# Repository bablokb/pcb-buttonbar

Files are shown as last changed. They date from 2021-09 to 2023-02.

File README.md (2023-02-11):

Project pcb-buttonbar
=====================

Overview
--------

This project contains the KiCAD files for a button-bar with
six buttons. Each button uses some additional hardware-components to
debounce the button:

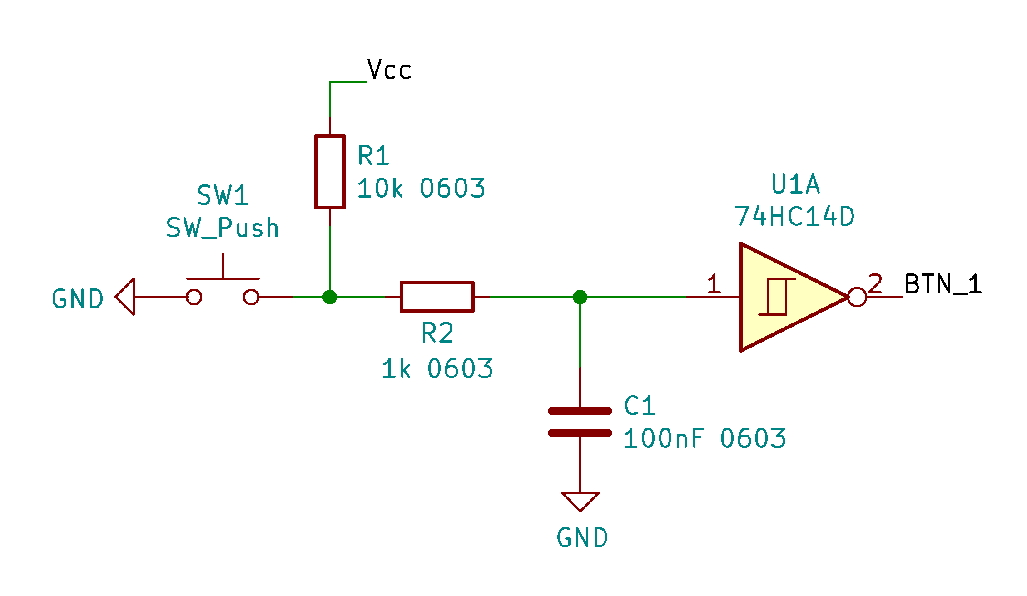
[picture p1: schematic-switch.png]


The buttons are pulled up using R1. R2 and C1 serve as a lowpass-filter,
i.e. high frequency bouncing is filtered out. The final inverter, a
74HC14 is a Schmitt-Trigger type inverter. This inverter switches from
high to low at a different level than from low to high (hysteresis),
so this will convert the curve from the RC-filter to sharp edge.

Goodies
-------

The buttonbar supports 6x6mm buttons and 12x12mm buttons. In addition
to the debounce-logic (bottom side of the pcb), there are optional
LEDs+resistors on the top.

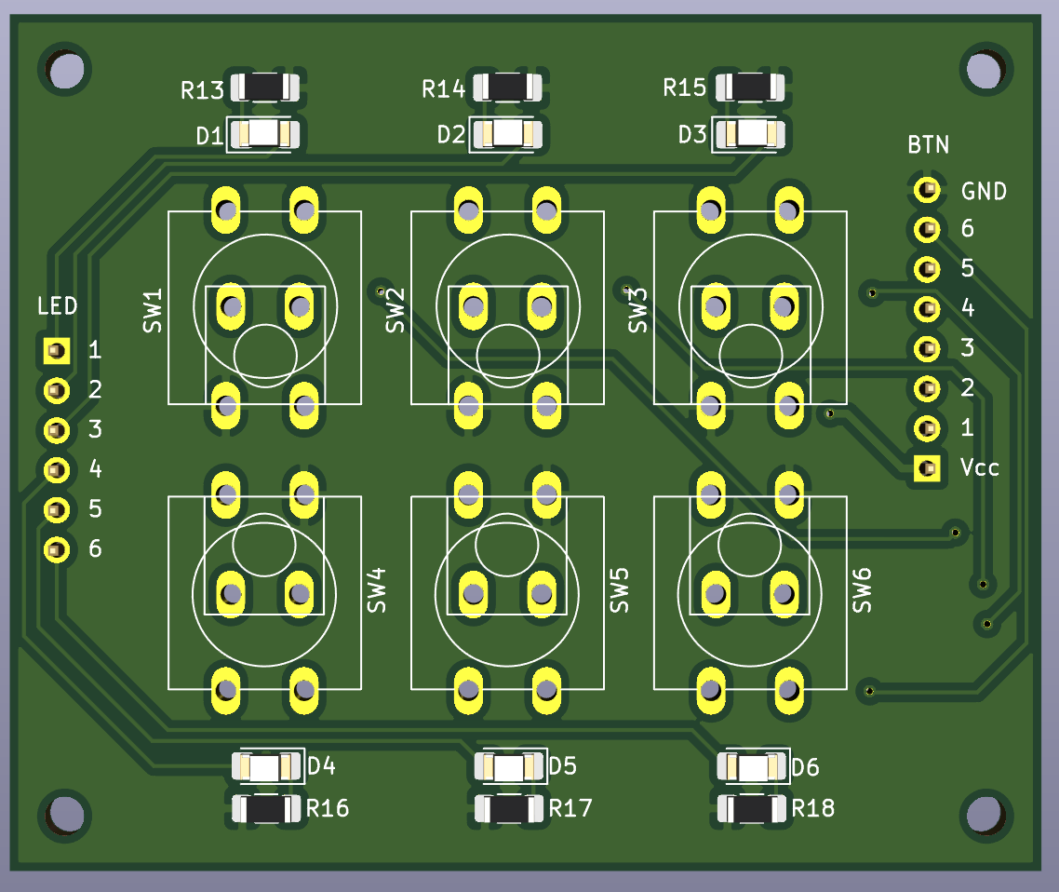
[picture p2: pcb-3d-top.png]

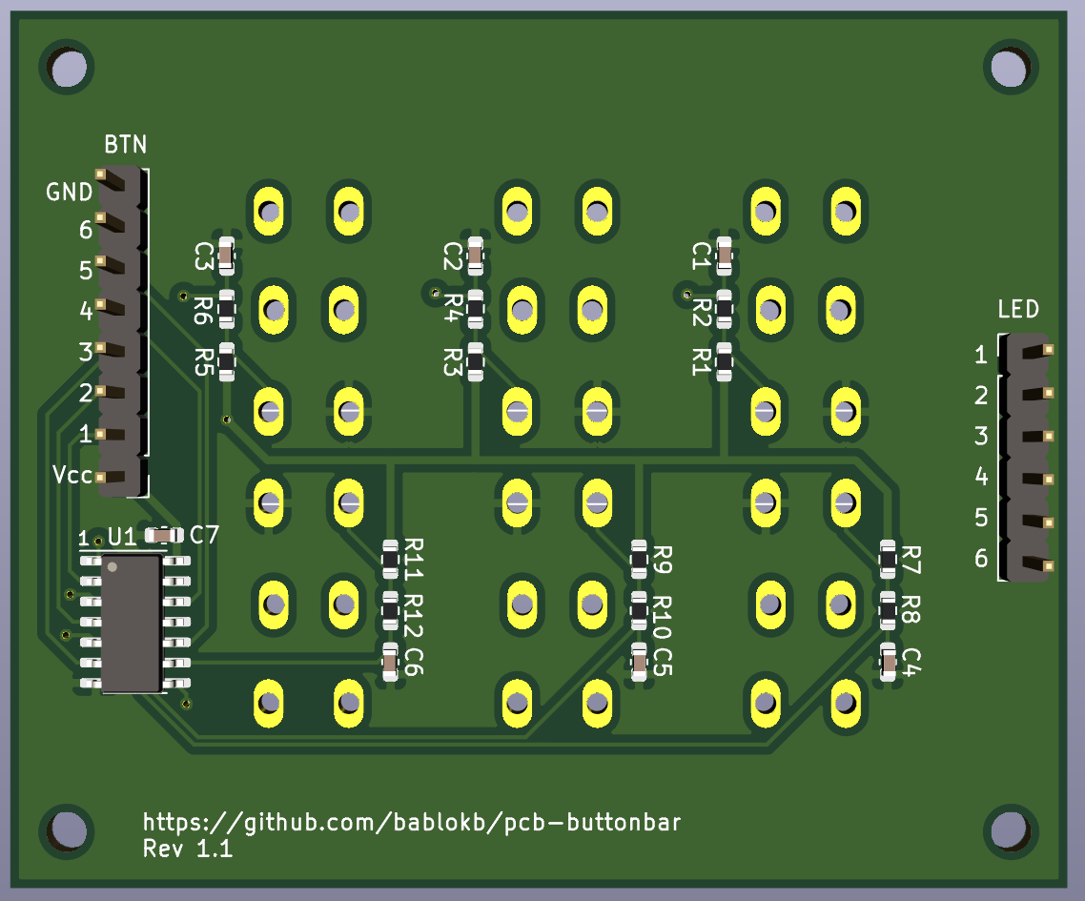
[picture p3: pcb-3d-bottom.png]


The footprints for the top-side are 1206, suitable for hand-soldering.
The bottom-side uses 0603, ideal for automatic assembly.

Checkout the branch "1x6-layout" for an alternatve button-layout.

Production Files
----------------

In the directory `production_files` you will find gerber-files, bom and cpl-file
suitable for JCLPCB. Migrating to a format suitable for your favorite
pcb-assembly service should be straightforward.

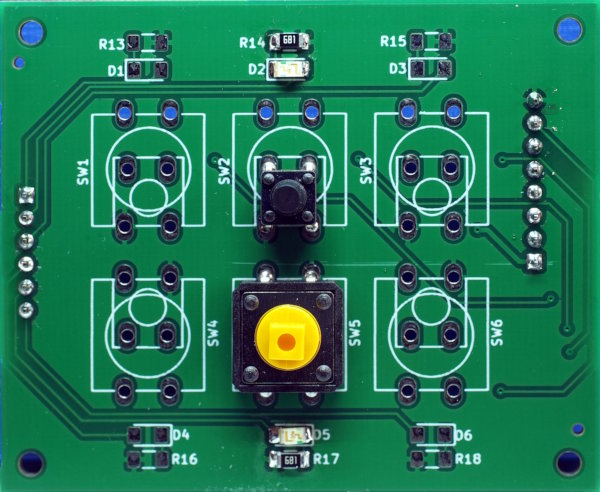
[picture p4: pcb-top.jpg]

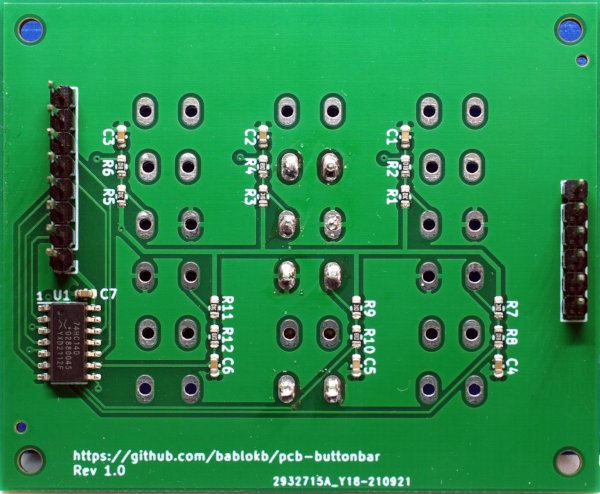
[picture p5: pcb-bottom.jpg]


Test Program
------------

The directory `src` contains a simple test program. Without the debouncing
in hardware, you would have to pass an additional parameter to the
Button-constructor for debouncing in software.

License
-------

Shield: [![CC BY-SA 4.0][cc-by-sa-shield]][cc-by-sa]

This work is licensed under a
[Creative Commons Attribution-ShareAlike 4.0 International
License][cc-by-sa].

[][cc-by-sa]

[cc-by-sa]: http://creativecommons.org/licenses/by-sa/4.0/
[cc-by-sa-image]: https://licensebuttons.net/l/by-sa/4.0/88x31.png
[cc-by-sa-shield]:
https://img.shields.io/badge/License-CC%20BY--SA%204.0-lightgrey.svg

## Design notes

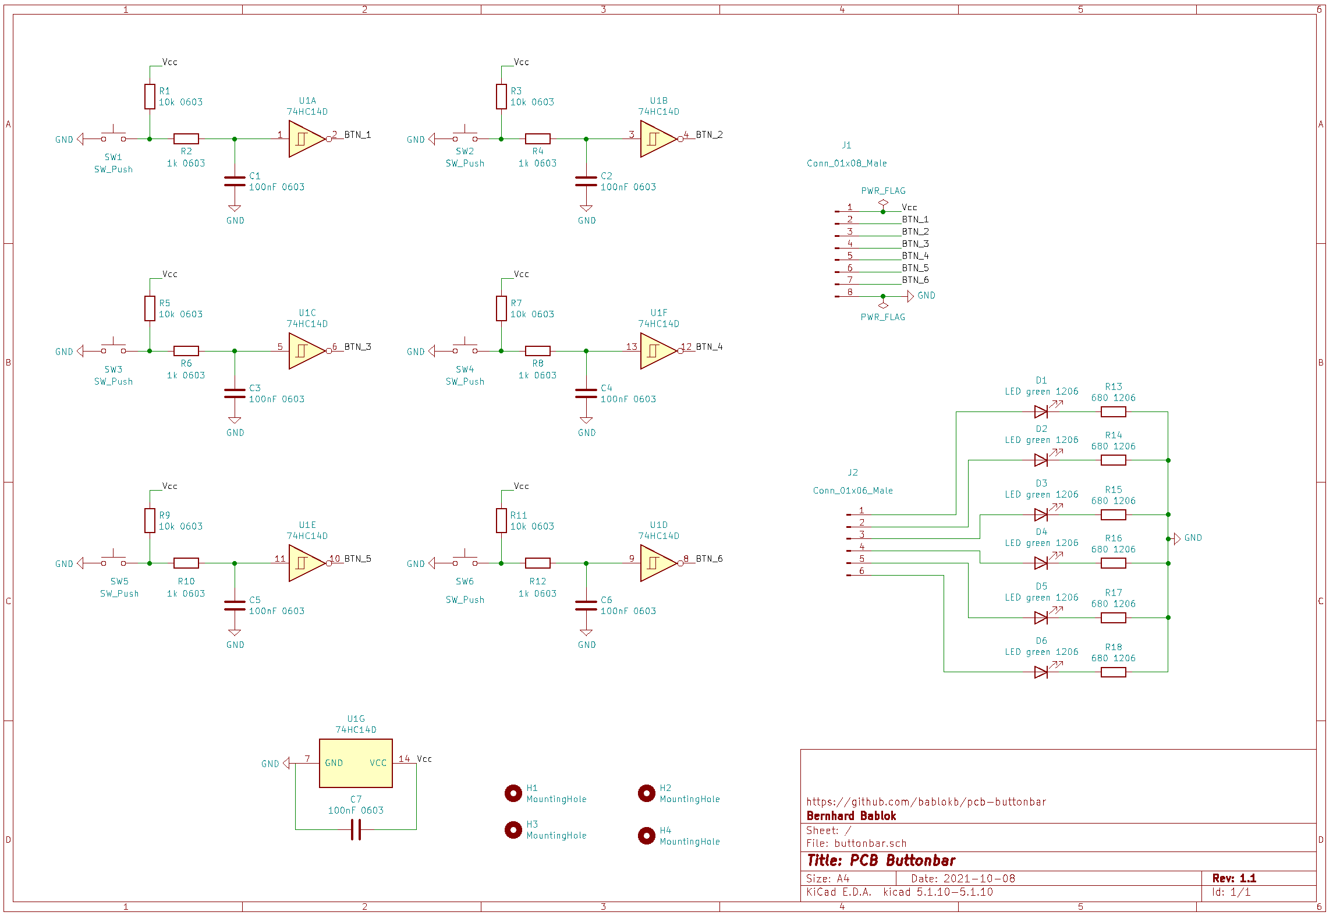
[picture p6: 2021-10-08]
schematic-complete.png

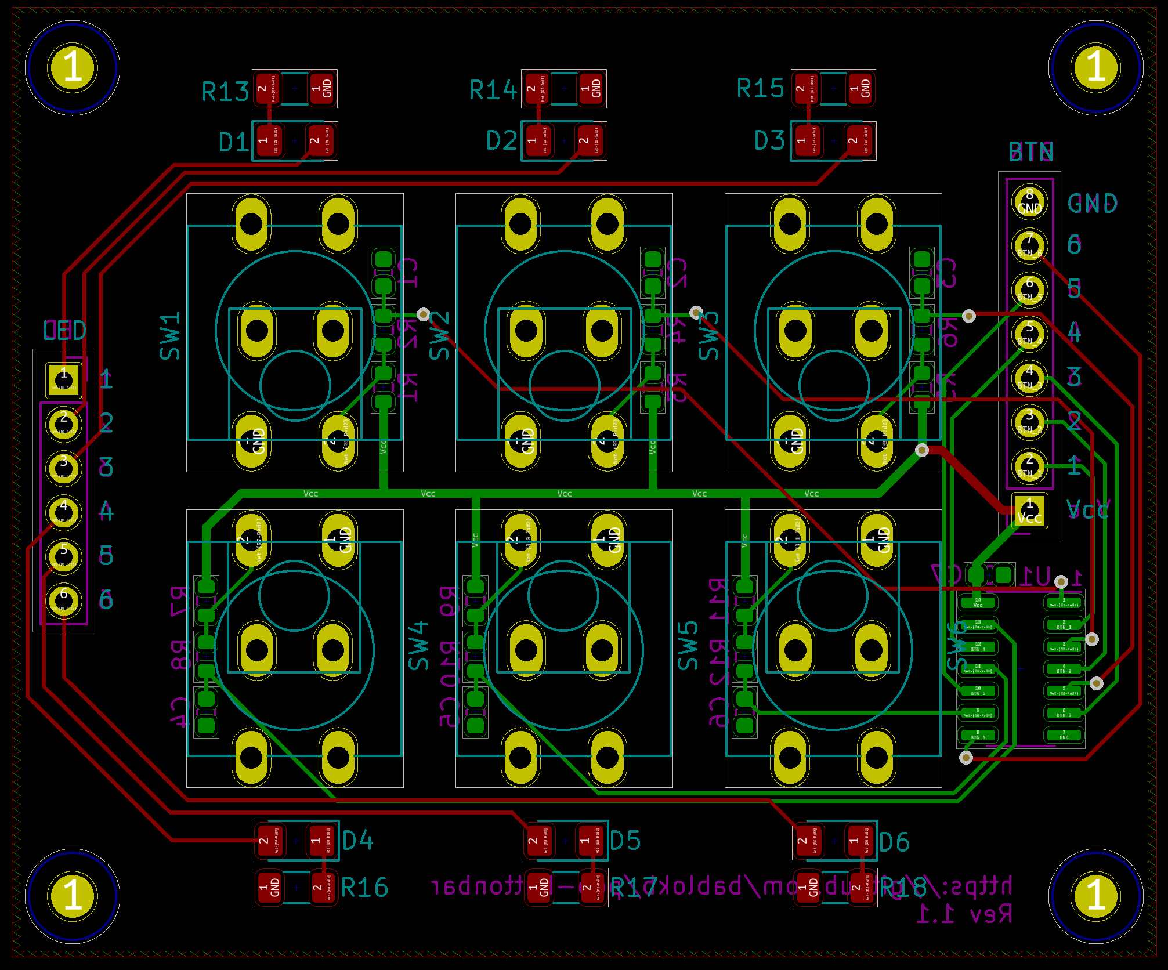
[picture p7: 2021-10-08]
layout.png

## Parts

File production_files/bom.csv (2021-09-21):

Comment | Designator | Footprint | LCSC
100nF 0603 | C1,C2,C3,C4,C5,C6,C7 | Capacitor_SMD:C_0603_1608Metric | C14663
LED green 1206 | D1,D2,D3,D4,D5,D6 | LED_SMD:LED_1206_3216Metric_Pad1.42x1.75mm_HandSolder
MountingHole | H1,H2,H3,H4 | MountingHole:MountingHole_2.5mm
Conn_01x08_Male | J1 | Connector_PinHeader_2.54mm:PinHeader_1x08_P2.54mm_Vertical
Conn_01x06_Male | J2 | Connector_PinHeader_2.54mm:PinHeader_1x06_P2.54mm_Vertical
10k 0603 | R1,R3,R5,R7,R9,R11 | Resistor_SMD:R_0603_1608Metric | C25804
680 1206 | R13,R14,R15,R16,R17,R18 | Resistor_SMD:R_1206_3216Metric_Pad1.30x1.75mm_HandSolder
1k 0603 | R2,R4,R6,R8,R10,R12 | Resistor_SMD:R_0603_1608Metric | C21190
SW_Push | SW1,SW2,SW3,SW4,SW5,SW6 | user:SW_PUSH-6.12mm
74HC14D | U1 | Package_SO:SOIC-14_3.9x8.7mm_P1.27mm | C5605

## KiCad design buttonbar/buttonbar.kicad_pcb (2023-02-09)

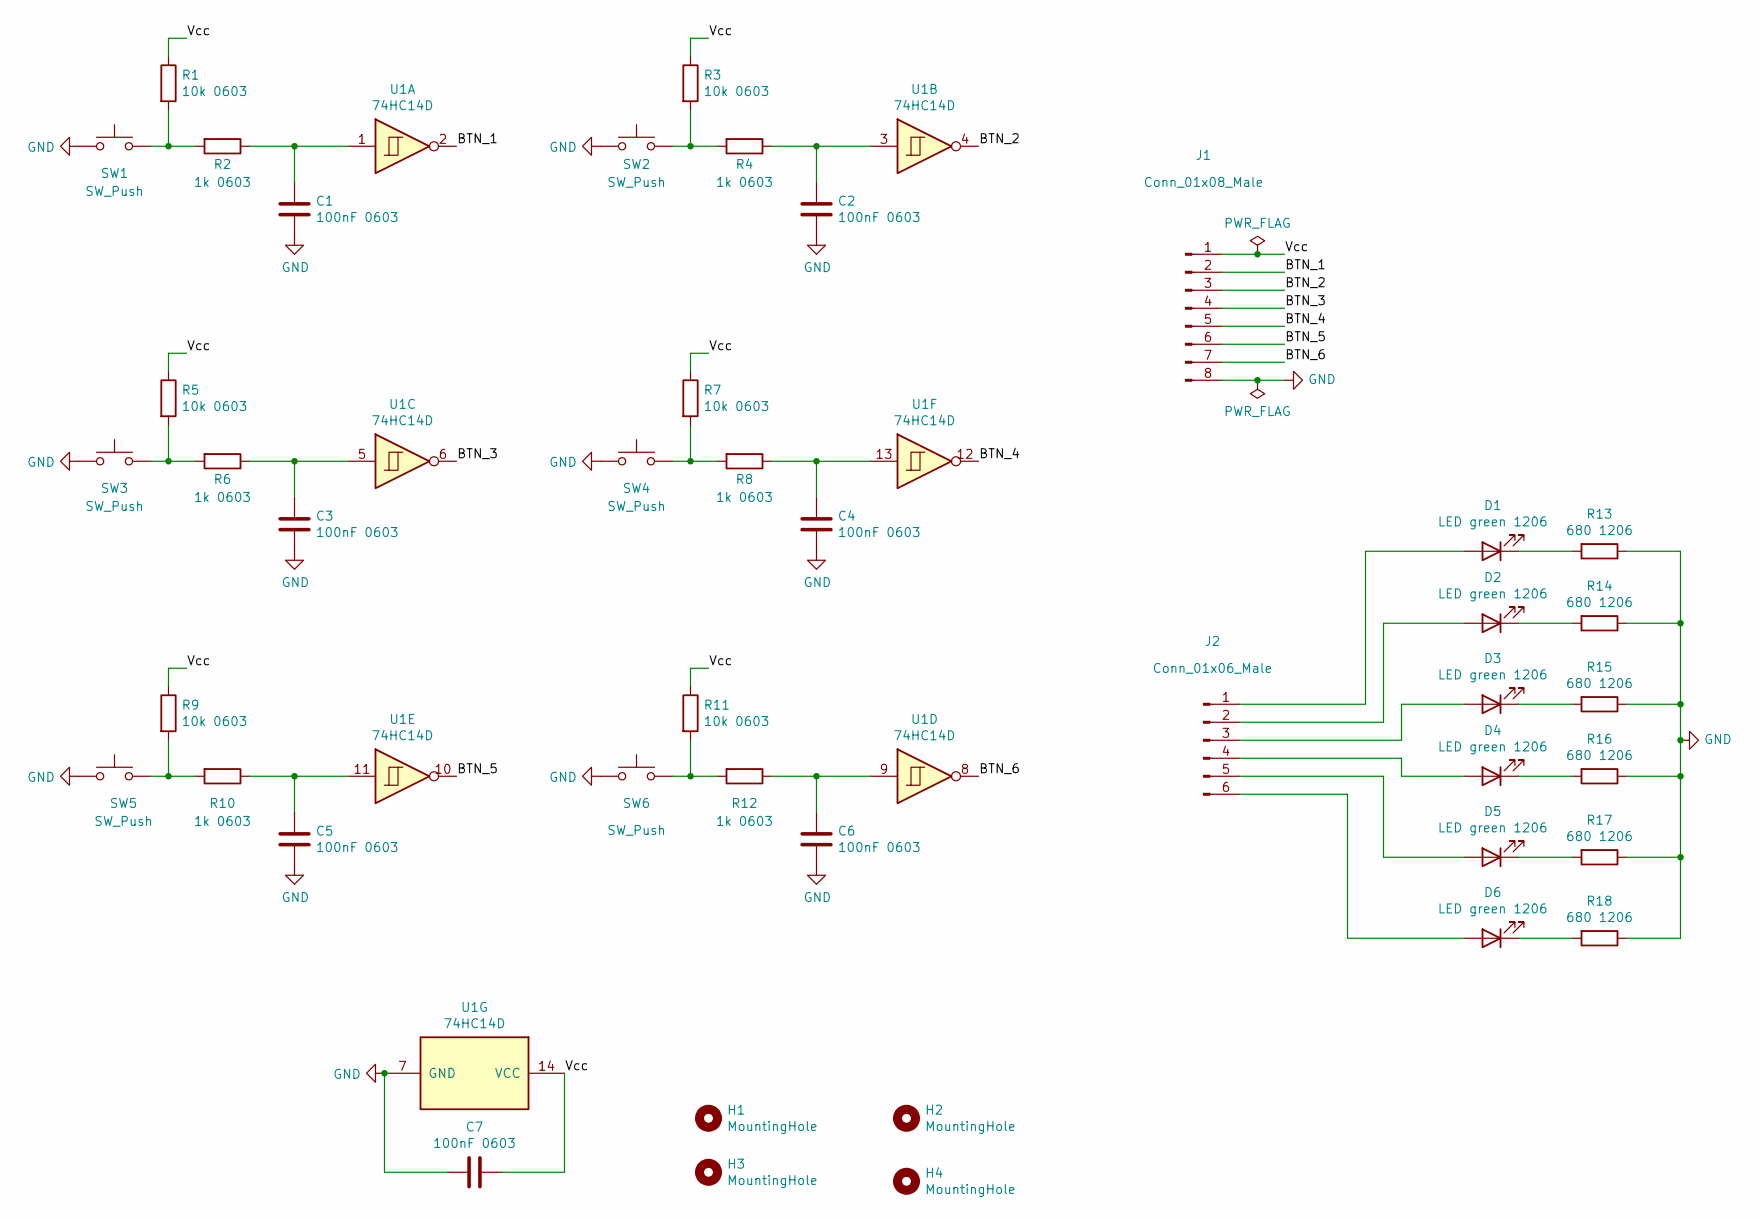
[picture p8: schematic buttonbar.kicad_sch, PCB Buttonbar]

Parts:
C1, C2, C3, C4, C5, C6, C7: 100nF 0603; C_0603_1608Metric; LCSC C14663
D1, D2, D3, D4, D5, D6: LED green 1206; LED_1206_3216Metric_Pad1.42x1.75mm_HandSolder
H1, H2, H3, H4: MountingHole; MountingHole_2.5mm
J1: Conn_01x08_Male; PinHeader_1x08_P2.54mm_Vertical
J2: Conn_01x06_Male; PinHeader_1x06_P2.54mm_Vertical
R1, R3, R5, R7, R9, R11: 10k 0603; R_0603_1608Metric; LCSC C25804
R2, R4, R6, R8, R10, R12: 1k 0603; R_0603_1608Metric; LCSC C21190
R13, R14, R15, R16, R17, R18: 680 1206; R_1206_3216Metric_Pad1.30x1.75mm_HandSolder
SW1, SW2, SW3, SW4, SW5, SW6: SW_Push; SW_PUSH-6.12mm
U1: 74HC14D; SOIC-14_3.9x8.7mm_P1.27mm; LCSC C5605

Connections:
/BTN_1: J1.2, U1.2
/BTN_2: J1.3, U1.4
/BTN_3: J1.4, U1.6
/BTN_4: J1.5, U1.12
/BTN_5: J1.6, U1.10
/BTN_6: J1.7, U1.8
/Vcc: C7.1, J1.1, R1.1, R3.1, R5.1, R7.1, R9.1, R11.1, U1.14 (VCC)
GND: C1.2, C2.2, C3.2, C4.2, C5.2, C6.2, C7.2, J1.8, R13.1, R14.1, R15.1, R16.1, R17.1, R18.1, SW1.1, SW2.1, SW3.1, SW4.1, SW5.1, SW6.1, U1.7 (GND)
unnamed: C1.1, R2.1, U1.1
unnamed: C2.1, R4.1, U1.3
unnamed: C3.1, R6.1, U1.5
unnamed: C4.1, R8.1, U1.13
unnamed: C5.1, R10.1, U1.11
unnamed: C6.1, R12.1, U1.9
unnamed: D1.1 (K), R13.2
unnamed: D1.2 (A), J2.1
unnamed: D2.1 (K), R14.2
unnamed: D2.2 (A), J2.2
unnamed: D3.1 (K), R15.2
unnamed: D3.2 (A), J2.3
unnamed: D4.1 (K), R16.2
unnamed: D4.2 (A), J2.4
unnamed: D5.1 (K), R17.2
unnamed: D5.2 (A), J2.5
unnamed: D6.1 (K), R18.2
unnamed: D6.2 (A), J2.6
unnamed: R1.2, R2.2, SW1.2
unnamed: R3.2, R4.2, SW2.2
unnamed: R5.2, R6.2, SW3.2
unnamed: R7.2, R8.2, SW4.2
unnamed: R9.2, R10.2, SW5.2
unnamed: R11.2, R12.2, SW6.2

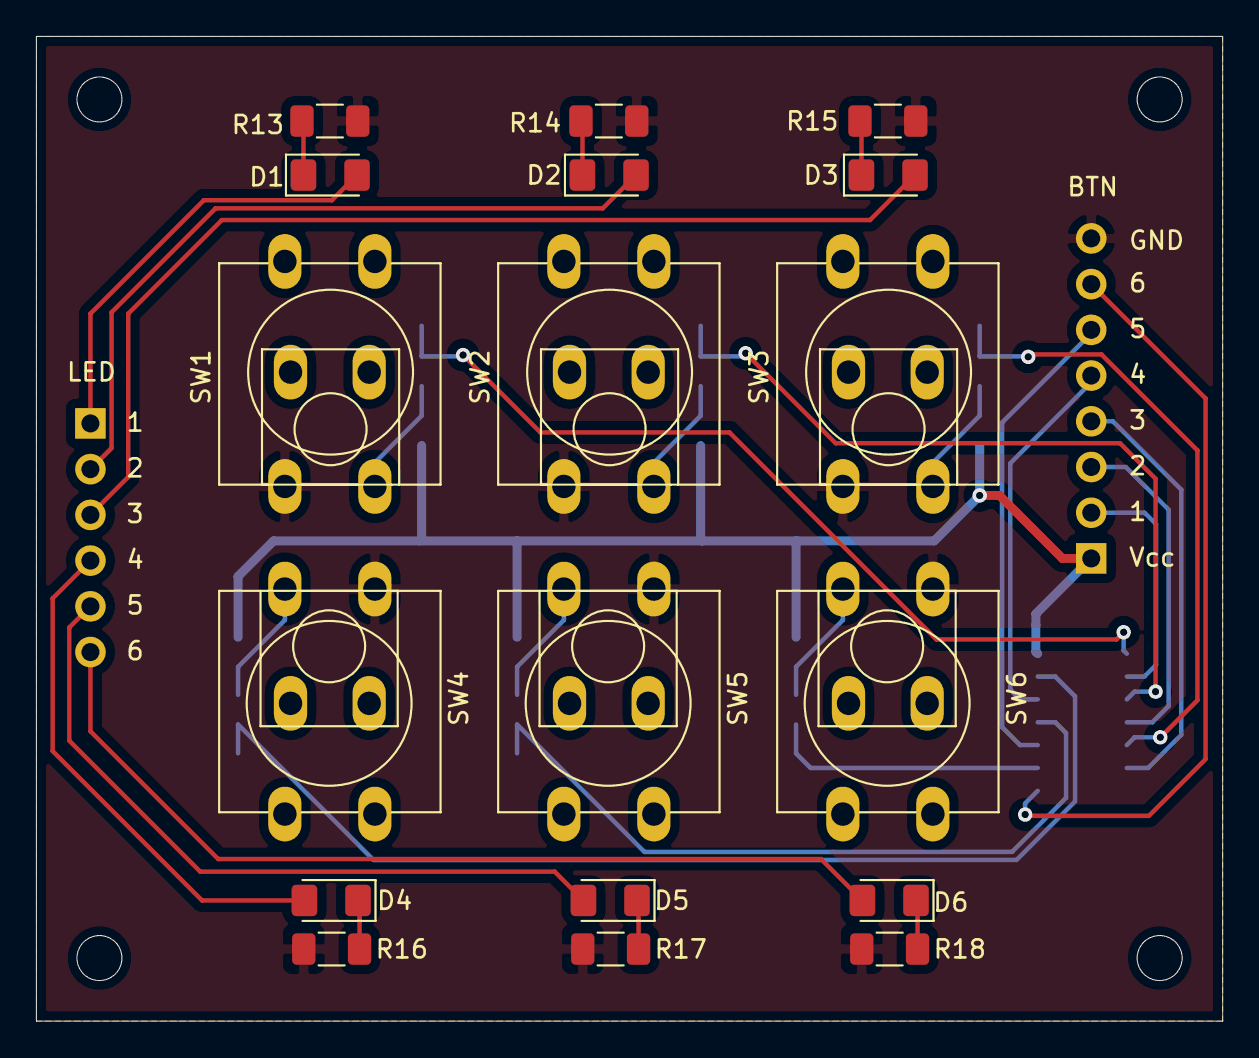
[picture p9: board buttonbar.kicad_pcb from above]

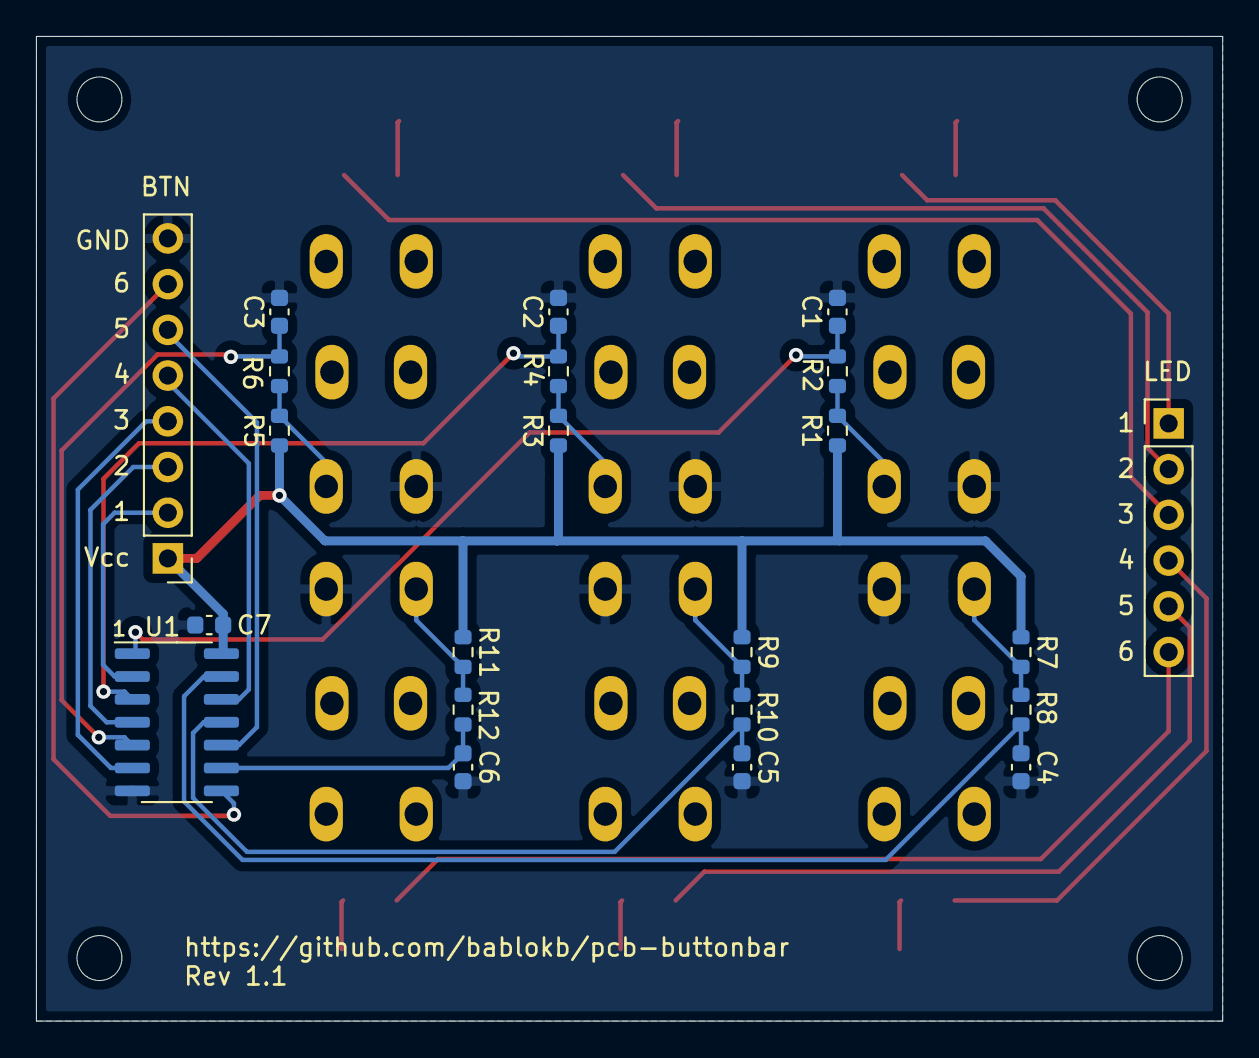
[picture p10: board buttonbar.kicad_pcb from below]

Board: 2 copper layers, 65.9 x 54.7 mm, 44 parts (22 on the bottom side), 32 nets.

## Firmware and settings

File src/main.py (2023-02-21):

# ----------------------------------------------------------------------------
# A simple test for the button-bar (CircuitPython version)
#
# Author: Bernhard Bablok
# License: GPL3
#
# Website: https://github.com/bablokb/pcb-buttonbar
#
# ----------------------------------------------------------------------------

import board
import time
from digitalio import DigitalInOut, Direction

PIN_BTN2 = board.GP10
PIN_BTN5 = board.GP11
PIN_LED2 = board.GP12
PIN_LED5 = board.GP13

btn2 = DigitalInOut(PIN_BTN2)
btn2.direction = Direction.INPUT
btn2.pull = None

btn5 = DigitalInOut(PIN_BTN5)
btn5.direction = Direction.INPUT
btn5.pull = None

led2 = DigitalInOut(PIN_LED2)
led2.direction = Direction.OUTPUT

led5 = DigitalInOut(PIN_LED5)
led5.direction = Direction.OUTPUT

while True:
  if btn2.value:
    led2.value = 1 - led2.value    # toggle button
    time.sleep(0.15)               # a button-press takes about 100ms
  if btn5.value:
    led5.value = 1 - led5.value
    time.sleep(0.15)

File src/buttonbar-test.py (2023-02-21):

#!/usr/bin/python3
# -*- coding: utf-8 -*-
# ----------------------------------------------------------------------------
# A simple test for the button-bar (Raspberry Pi version)
#
# Author: Bernhard Bablok
# License: GPL3
#
# Website: https://github.com/bablokb/pcb-buttonbar
#
# ----------------------------------------------------------------------------

from gpiozero import Button, LED
import signal

btn2 = Button(24,pull_up=None,active_state=True)
btn5 = Button(23,pull_up=None,active_state=True)

led2 = LED(17)
led5 = LED(27)

btn2.when_pressed = lambda: led2.toggle()
btn5.when_pressed = lambda: led5.toggle()

signal.pause()

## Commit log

2021-10-08 Rev 1.1: added labels (no functional change)
    [buttonbar-B_Cu.gbr, buttonbar-B_Mask.gbr, buttonbar-B_SilkS.gbr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]
2023-02-09 migrated to Kicad 6
    [buttonbar.kicad_pcb, buttonbar.kicad_sch, buttonbar.sch]
2023-02-11 renamed 'jlcpcb' to 'production_files'
    [bom.csv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]
